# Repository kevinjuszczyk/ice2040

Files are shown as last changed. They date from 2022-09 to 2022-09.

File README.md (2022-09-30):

# ICE2040
ICE40UP5K FPGA + RP2040 Hacker Board
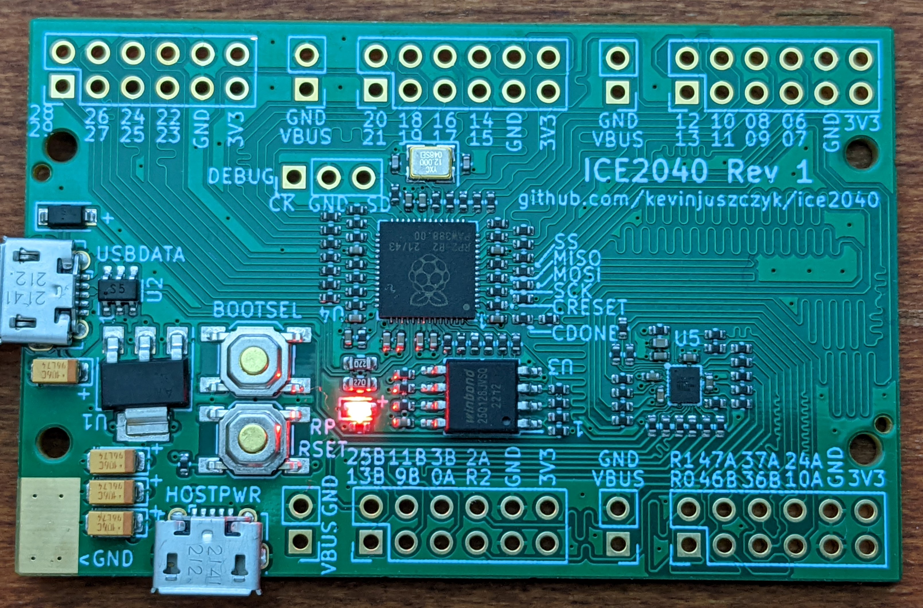
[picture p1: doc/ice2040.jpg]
ice2040


## Overview
The ICE2040 combines a Lattice ICE40UP5K FPGA with a Raspberry Pi RP2040. The RP2040 is used to configure the ICE40 SRAM, and optionally provide a clock or host communication. Pmod connectors are provided for both the ICE40 and RP2040, with the rightmost connectors lined up in such a way that up to 16 additional lines between the ICE40 and RP2040 can be bridged together using a PCB or ribbon cable.

## Background
A friend expressed an interest in implementing a RISC-V processor using an FPGA, something like [learn-fpga](https://github.com/BrunoLevy/learn-fpga/blob/master/FemtoRV/TUTORIALS/FROM_BLINKER_TO_RISCV/README.md). Due to the ongoing parts shortage, many of the low-end FPGA dev boards are either out of stock, or have moved out of the pocket change price range. With an eye toward building a board using whatever might still be in stock, I found that the major retailers have many thousands of ICE40 parts in fine pitch BGA packages. I started playing around in KiCad with the ICE40UP5K-UWG30 (30-ball 0.4mm pitch) part to see if there was a way to fan out enough of the pins to make a reasonably useful board. By modifying the shape of the pads, I was able to achieve a complete fanout that can be fabricated with JLCPCB's 4-layer process. Most boards like this use an FTDI serial converter for host communication and FPGA configuration, but these have also been hard to get. I decided to use an RP2040 for these functions, since they are in stock and much less expensive. 
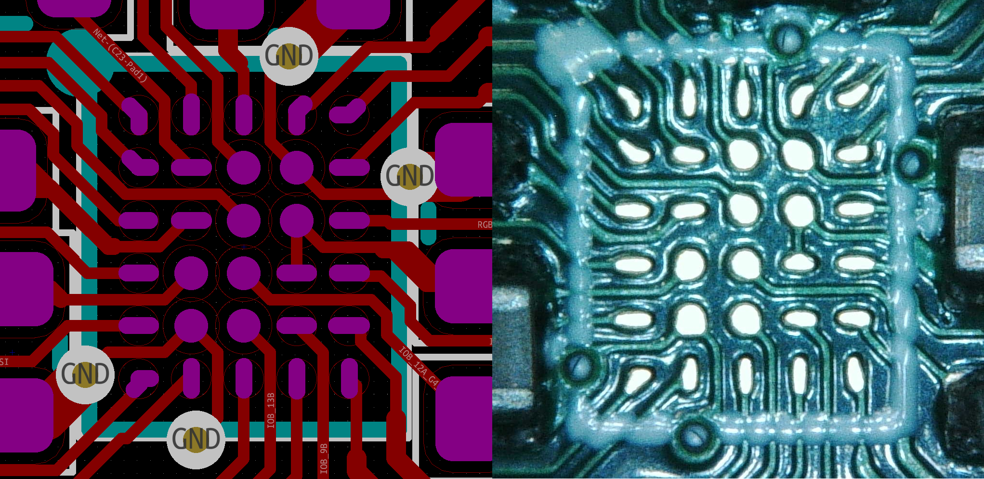
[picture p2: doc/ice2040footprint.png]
ice2040footprint


## Build
#### PCB
The board can be fabricated using [JLCPCB's](https://jlcpcb.com/) 4-layer process, and all components assembled (except for the ICE40 and Pmod headers) using their Economic PCBA service. [Jlcfab.zip](./kicad/jlcfab.zip) contains the fabrication files including the BOM, footprint position, drill, and Gerber files. [Jlcboardsettings.txt](./kicad/jlcboardsettings.txt) shows how to configure the JLCPCB order screen. Note that you want to specify the technical review (Confirm Production Files) for both the board fabrication and assembly. This will let JLCPCB adjust the board traces and parts orientation as needed.

NOTE: If you haven't soldered BGA packages before, this is *not* a good one to start with.
1. When the board arrives, check that the RP2040 is functioning correctly by plugging it into the USB port of your PC. A new removable drive should pop up with the volume name of RPI-RP2.
2. Unplug the board.
3. To hand-solder the ICE40, cover the pads of the ICE40 footprint with a thin layer of tacky flux. If too much flux is used, it will boil when heated and dislodge the balls from the package. 
4. Smear a thin layer of solder paste on a flat metal surface, and then press the ICE40 into it. The idea is to get some paste to stick to the balls so that when heat is applied, the paste will flow down and pool on the pads. 
5. Place the ICE40 on the board and line up the package inside the silkscreen while making sure it stays flat on the board. 
6. Reflow either with an oven or by using a hotplate underneath and a heat gun above. 
7. Check that all pins are connected by using the multimeter diode check. Connect the positive lead to board ground, and then touch each ICE40 Pmod pad with the negative lead. A good connection will show a voltage drop between 0.5 to 0.7 volts. Test for continuity between the power rails and ground to make sure they are not shorted. 
8. If you find an open connection, it may be possible to save the part. Dissolve some tacky flux with an equal amount of 99% isopropyl. Drip this mixture around the perimeter of the part so that it wicks underneath. Soak up any excess with a paper towel, and let the flux dry for several hours. Reflow again.

#### Software
1. Hold down the BOOTSEL button on the board while you plug the board into your PC. Once the RPI-RP2 drive pops up, you can release the button.
2. Download the latest release of [CircuitPython](https://circuitpython.org/board/raspberry_pi_pico/)
3. Copy the .UF2 file to the RPI-RP2 drive.
4. The ICE2040 will reboot and a drive labeled CIRCUITPY will pop up.
5. Copy the [top_bitmap.bin](./icecube2/multiblink/multiblink_Implmnt/sbt/outputs/bitmap/top_bitmap.bin) file to the CIRCUITPY drive. This is an ICE40 FPGA bitstream designed to blink several LEDs on the bottom center Pmod port (labeled 25B, 13B, etc.)
6. Copy the [code.py](./circuitpython/code.py) file to the CIRCUITPY drive, overwriting the existing file. This is a python script designed to upload the top_bitmap.bin file into the ICE40.
7. If you have an LED Pmod plugged into the bottom center Pmod port, you should now see several LEDs blinking at various rates. A multimeter can also be used to check for correct operation. Pins 13B or 25B change slowly enough to show the voltage alternate between 0 and 3.3 volts.
8. CircuitPython will automatically run the code.py script whenever a file on the CIRCUITPY drive is changed (including top_bitmap.bin). A serial port is also provided for communication with the host PC. See the CircuitPython [documentation](https://learn.adafruit.com/welcome-to-circuitpython) for details.


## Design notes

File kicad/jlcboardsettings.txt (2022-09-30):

Base Material: FR-4

Layers: 4

Dimension: 63.5 mm* 40.6 mm

Product Type: Industrial/Consumer electronics

Different Design: 1

Delivery Fomat: Single PCB

PCB Thickness: 1.6

Impedance: yes JLC3313

PCB Color: Green

Silkscreen: White

Surface Finish: ENIG

Deburring/Edge rounding: No

Outer Copper Weight: 1

Inner Copper Weight: 0.5

Gold Fingers: No

Flying Probe Test: Fully Test

Castellated Holes: no

Remove Order Number: No

Min hole size/diameter:0.2/0.45mm↑

4-Wire Kelvin Test:No

Material Type:FR4-Standard Tg 130-140C

Paper between PCBs:No

Appearance Quality:IPC Class 2 Standard

Confirm Production file:Yes

Silkscreen Technology:Ink-jet/Screen Printing Silkscreen

Package Box:With JLCPCB logo

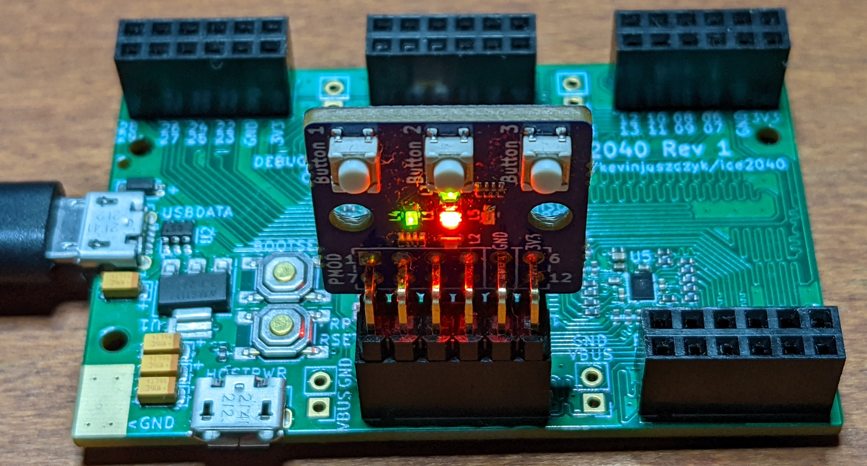
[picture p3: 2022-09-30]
doc/ice2040bg.png

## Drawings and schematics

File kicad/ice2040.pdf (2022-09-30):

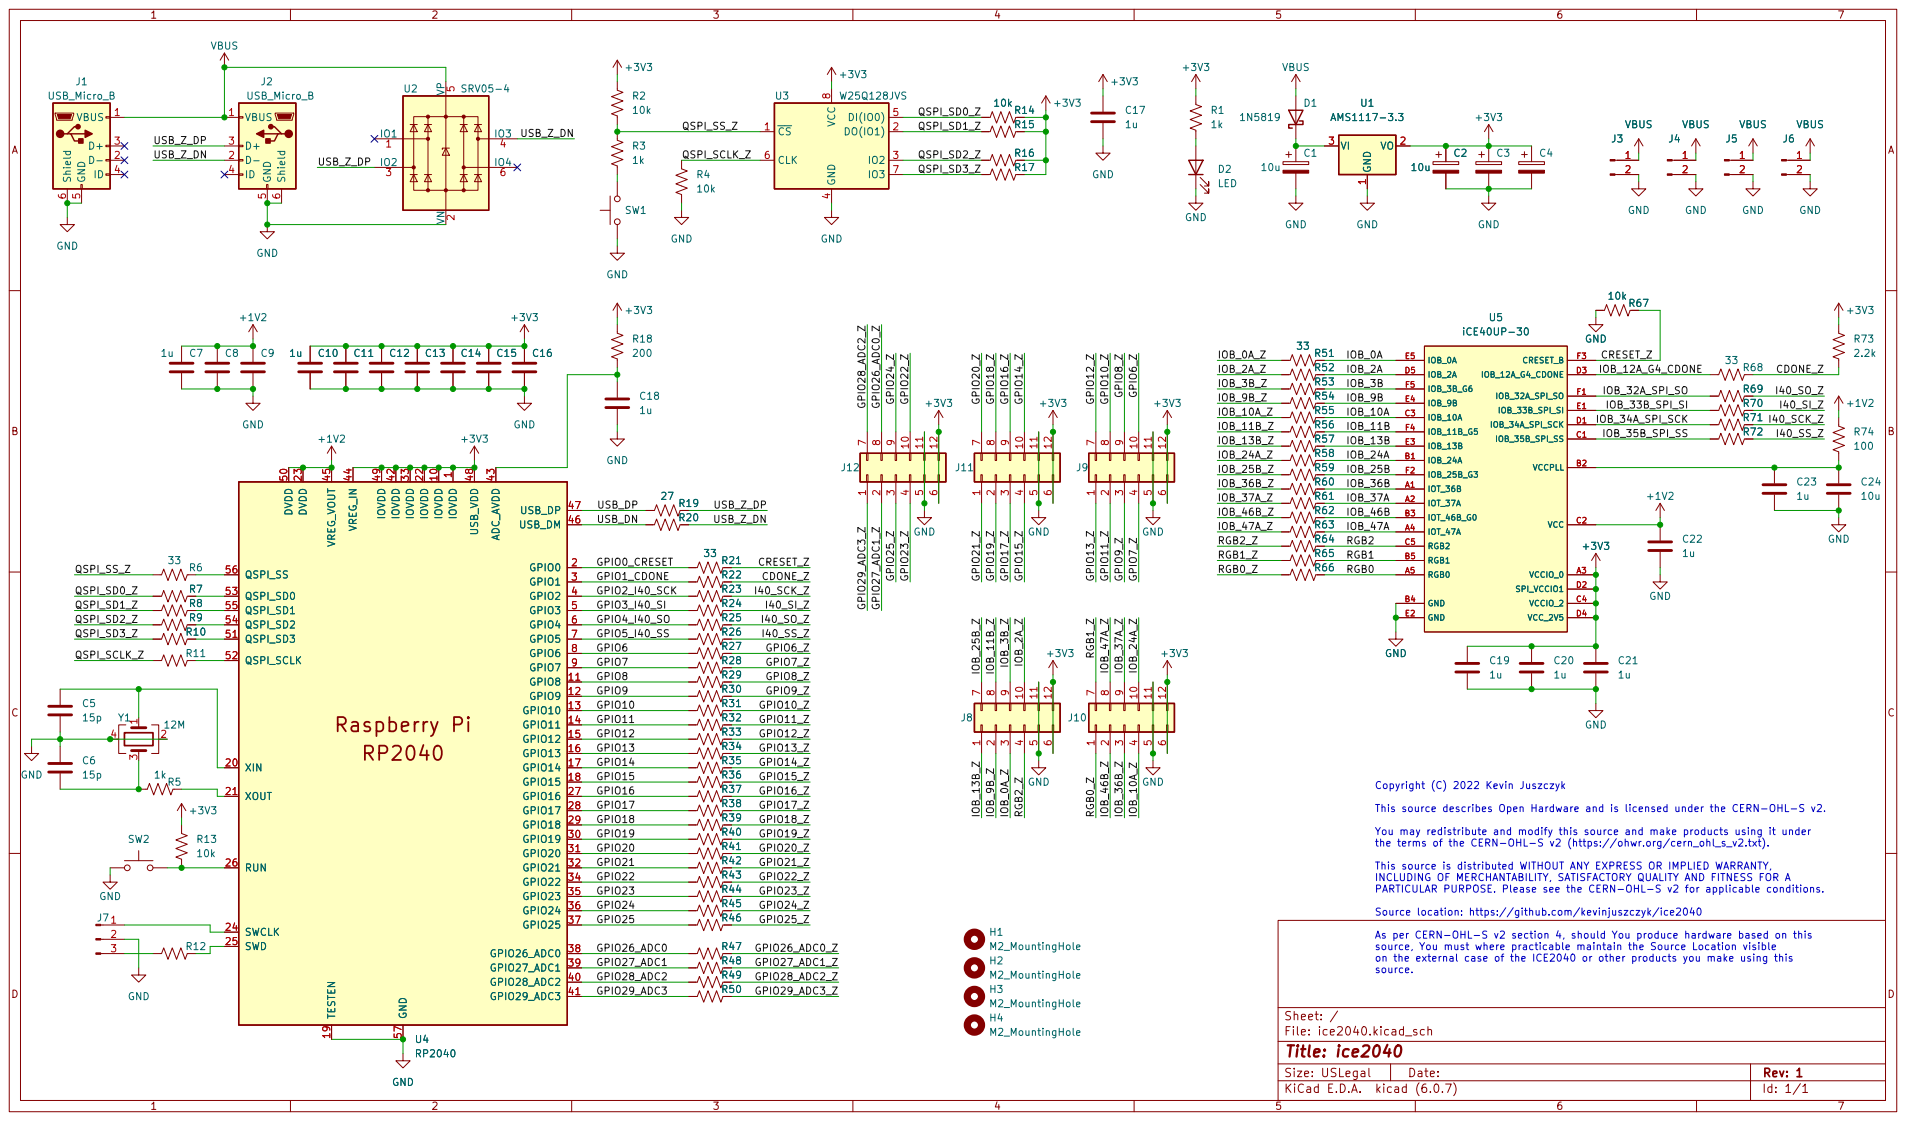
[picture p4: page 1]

1 IOVDD 10 GPIO8 11 GPIO9 12 GPIO10 13 GPIO11 14 GPIO12 15 GPIO13 16 GPIO14 17 GPIO15 18 TESTEN 19 GPIO0 2 XIN 20 XOUT 21 IOVDD 22 DVDD 23 SWCLK 24 SWD 25 RUN 26 GPIO16 27 GPIO17 28 GPIO18 29 GPIO1 3 GPIO19 30 GPIO20 31 GPIO21 32 IOVDD 33 GPIO22 34 GPIO23 35 GPIO24 36 GPIO25 37 GPIO26_ADC0 38 GPIO27_ADC1 39 GPIO2 4 GPIO28_ADC2 40 GPIO29_ADC3 41 IOVDD 42 ADC_AVDD 43 VREG_IN 44 VREG_VOUT 45 USB_DM 46 USB_DP 47 USB_VDD 48 IOVDD 49 GPIO3 5 DVDD 50 QSPI_SD3 51 QSPI_SCLK 52 QSPI_SD0 53 QSPI_SD2 54 QSPI_SD1 55 QSPI_SS 56 GND 57 GPIO4 6 GPIO5 7 GPIO6 8 GPIO7 9 U4RP2040

1 IOVDD 10 GPIO8 11 GPIO9 12 GPIO10 13 GPIO11 14 GPIO12 15 GPIO13 16 GPIO14 17 GPIO15 18 TESTEN 19 GPIO0 2 XIN 20 XOUT 21 IOVDD 22 DVDD 23 SWCLK 24 SWD 25 RUN 26 GPIO16 27 GPIO17 28 GPIO18 29 GPIO1 3 GPIO19 30 GPIO20 31 GPIO21 32 IOVDD 33 GPIO22 34 GPIO23 35 GPIO24 36 GPIO25 37 GPIO26_ADC0 38 GPIO27_ADC1 39 GPIO2 4 GPIO28_ADC2 40 GPIO29_ADC3 41 IOVDD 42 ADC_AVDD 43 VREG_IN 44 VREG_VOUT 45 USB_DM 46 USB_DP 47 USB_VDD 48 IOVDD 49 GPIO3 5 DVDD 50 QSPI_SD3 51 QSPI_SCLK 52 QSPI_SD0 53 QSPI_SD2 54 QSPI_SD1 55 QSPI_SS 56 GND 57 GPIO4 6 GPIO5 7 GPIO6 8 GPIO7 9 R19 27 R20 R22 R21 33 R24 R23 R27 R26 R25 R42 R44 R41 R39 R40 R43 R45 R46 R47 R50 R49 R48

This source describes Open Hardware and is licensed under the CERN-OHL-S v2.

You may redistribute and modify this source and make products using it under
the terms of the CERN-OHL-S v2 (https://ohwr.org/cern_ohl_s_v2.txt). This source is distributed WITHOUT ANY EXPRESS OR IMPLIED WARRANTY,

INCLUDING OF MERCHANTABILITY, SATISFACTORY QUALITY AND FITNESS FOR A PARTICULAR PURPOSE. Please see the CERN-OHL-S v2 for applicable conditions.

Source location: https://github.com/kevinjuszczyk/ice2040

As per CERN-OHL-S v2 section 4, should You produce hardware based on this
source, You must where practicable maintain the Source Location visible
on the external case of the ICE2040 or other products you make using this source.

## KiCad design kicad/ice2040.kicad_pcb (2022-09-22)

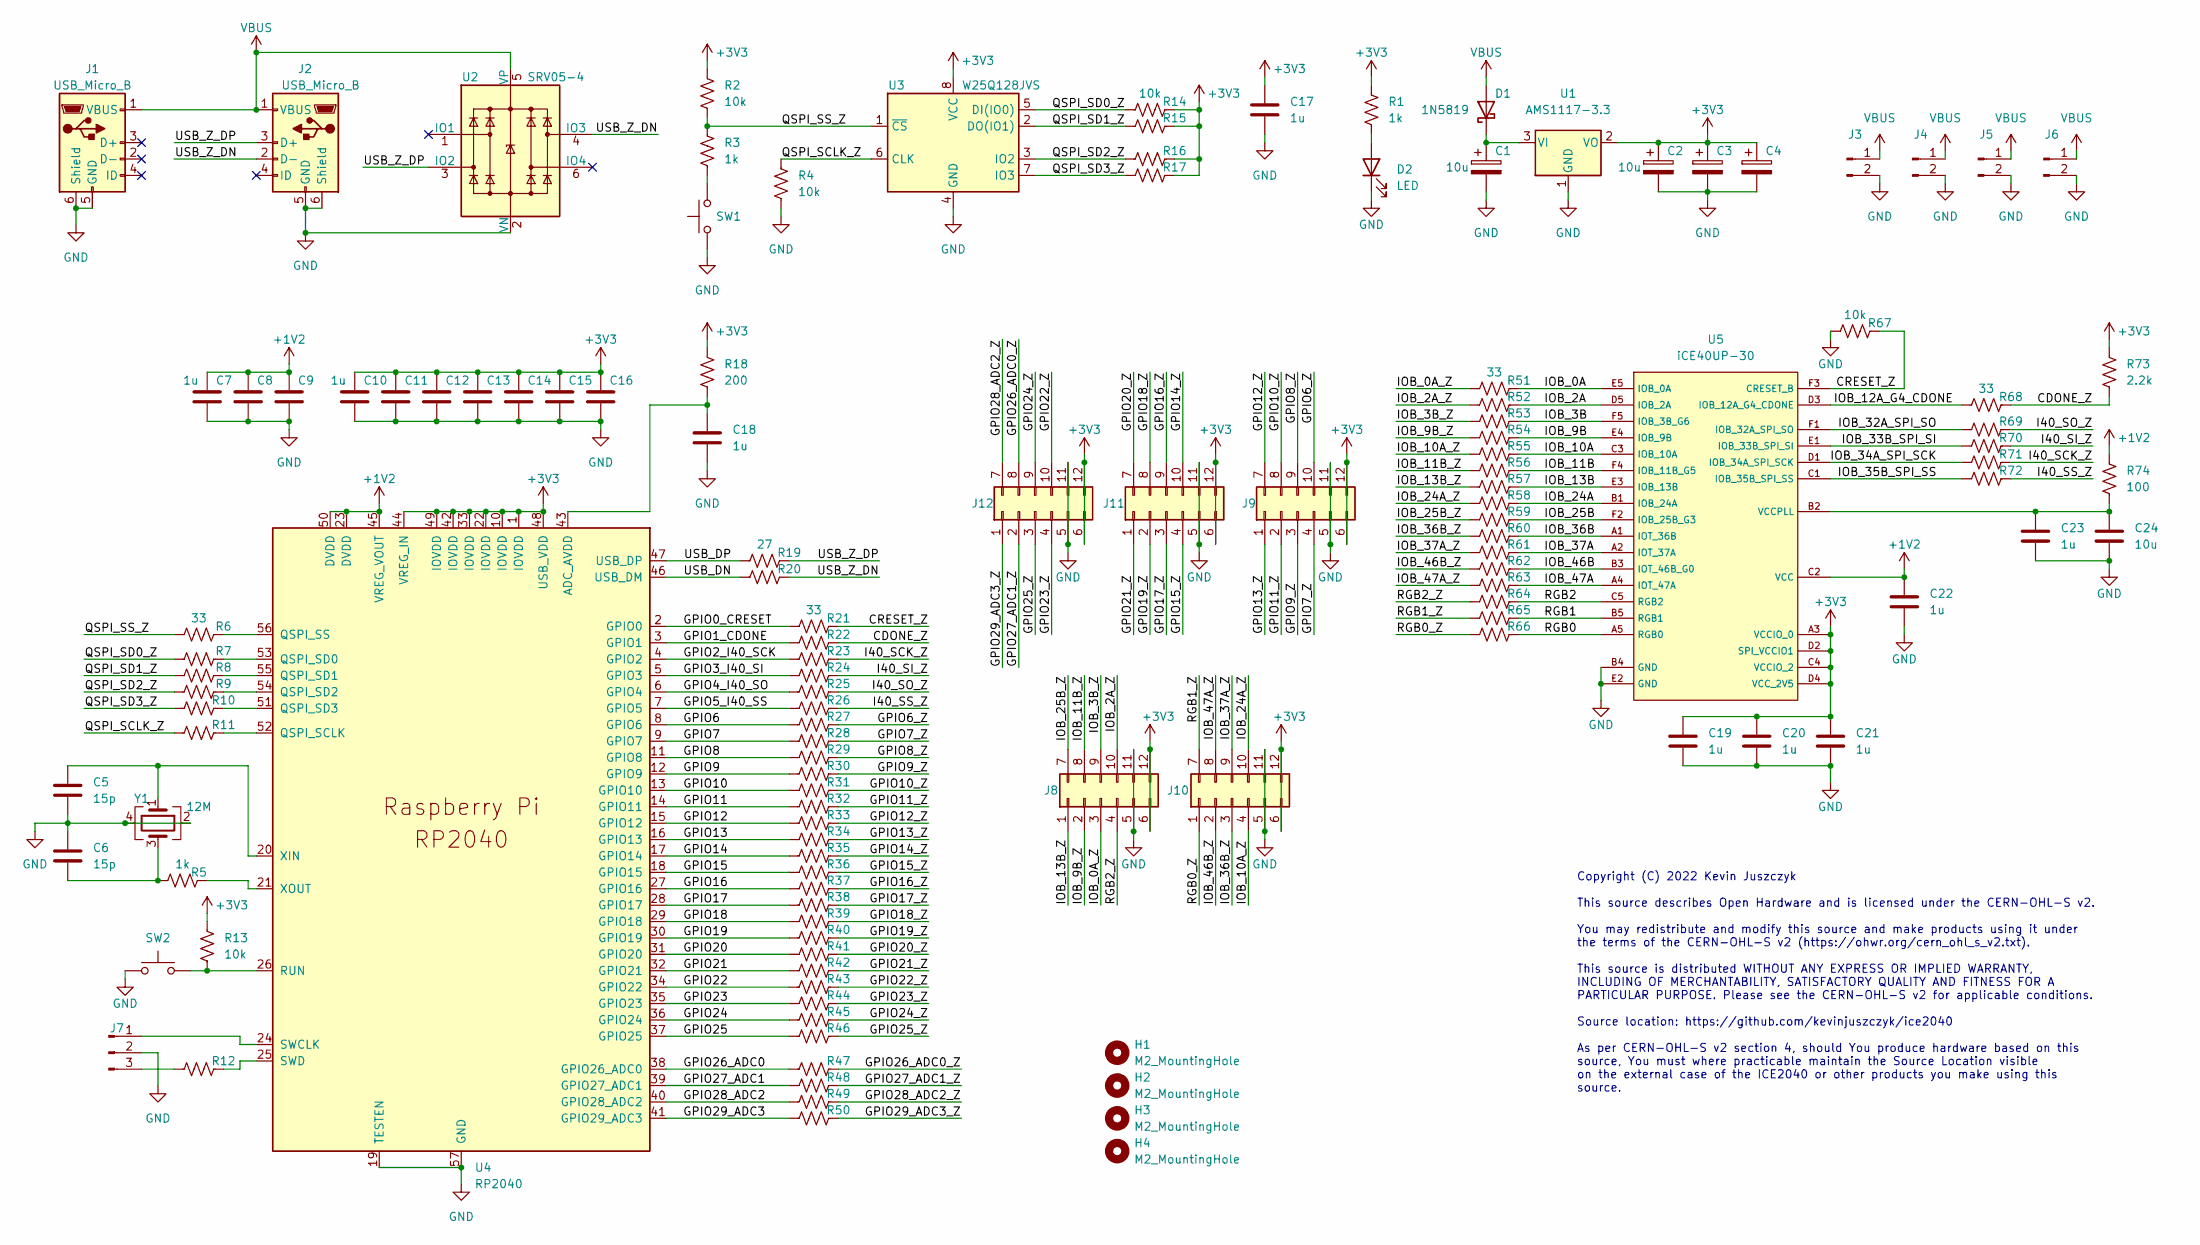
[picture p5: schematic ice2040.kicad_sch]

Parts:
C1, C2, C3, C4: 10u; CP_EIA-3216-18_Kemet-A; LCSC C7171
C5, C6: 15p; C_0402_1005Metric; LCSC C1548
C7, C8, C9, C10, C11, C12, C13, C14, C15, C16, C17, C18, C19, C20, C21, C22, C23: 1u; C_0402_1005Metric; LCSC C52923
C24: 10u; C_0402_1005Metric; LCSC C15525
D1: 1N5819; D_SOD-123; LCSC C8598
D2: LED; D_0603_1608Metric; LCSC C2286
H1, H2, H3, H4: M2_MountingHole; MountingHole_2.2mm_M2_ISO7380
J1, J2: USB_Micro_B; USB_Micro-B_Molex-105017-0001; LCSC C136000
J3, J4, J5, J6: 1x02_P2.54; PinHeader_1x02_P2.54mm_Vertical
J7: 1x03_P2.54; PinHeader_1x03_P2.54mm_Vertical
J8, J9, J10, J11, J12: PMOD_HOST
R1, R3, R5: 1k; R_0402_1005Metric; LCSC C11702
R2, R4, R13, R14, R15, R16, R17, R67: 10k; R_0402_1005Metric; LCSC C25744
R6, R7, R8, R9, R10, R11, R12, R21, R22, R23, R24, R25, R26, R27, R28, R29, R30, R31, R32, R33, R34, R35, R36, R37, R38, R39, R40, R41, R42, R43, R44, R45, R46, R47, R48, R49, R50, R51, R52, R53, R54, R55, R56, R57, R58, R59, R60, R61, R62, R63, R64, R65, R66, R68, R69, R70, R71, R72: 33; R_0402_1005Metric; LCSC C25105
R18: 200; R_0402_1005Metric; LCSC C25087
R19, R20: 27; R_0603_1608Metric; LCSC C25190
R73: 2.2k; R_0402_1005Metric; LCSC C25879
R74: 100; R_0402_1005Metric; LCSC C25076
SW1, SW2: SW_Push; SW_SPST_SKQG_WithoutStem; LCSC C318884
U1: AMS1117-3.3; SOT-223-3_TabPin2; LCSC C6186
U2: SRV05-4; SOT-23-6; LCSC C85364
U3: W25Q128JVS; SOIC-8_5.23x5.23mm_P1.27mm; LCSC C97521
U4: RP2040; QFN-56-1EP_7x7mm_P0.4mm_EP3.2x3.2mm_MoreThermalVias; LCSC C2040
U5: iCE40UP-30; BGA-30_5x6_2.114x2.537mm; LCSC C1519053
Y1: 12M; Crystal_SMD_SeikoEpson_FA238-4Pin_3.2x2.5mm; LCSC C9002

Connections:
+1V2: C7.1, C8.1, C9.1, C22.1, R74.2, U4.23 (DVDD), U4.45 (VREG_VOUT), U4.50 (DVDD), U5.C2 (VCC)
+3V3: C2.1, C3.1, C4.1, C10.1, C11.1, C12.1, C13.1, C14.1, C15.1, C16.1, C17.1, C19.1, C20.1, C21.1, J8.6, J8.12, J9.6, J9.12, J10.6, J10.12, J11.6, J11.12, J12.6, J12.12, R1.2, R2.2, R13.2, R14.1, R15.1, R16.1, R17.1, R18.2, R73.2, U1.2 (VO), U3.8 (VCC), U4.1 (IOVDD), U4.10 (IOVDD), U4.22 (IOVDD), U4.33 (IOVDD), U4.42 (IOVDD), U4.44 (VREG_IN), U4.48 (USB_VDD), U4.49 (IOVDD), U5.A3 (VCCIO_0), U5.C4 (VCCIO_2), U5.D2 (SPI_VCCIO1), U5.D4 (VCC_2V5)
/CDONE_Z: R22.1, R68.1, R73.1
/CRESET_Z: R21.1, R67.1, U5.F3 (CRESET_B)
/GPIO0_CRESET: R21.2, U4.2 (GPIO0)
/GPIO1_CDONE: R22.2, U4.3 (GPIO1)
/GPIO2_I40_SCK: R23.2, U4.4 (GPIO2)
/GPIO3_I40_SI: R24.2, U4.5 (GPIO3)
/GPIO4_I40_SO: R25.2, U4.6 (GPIO4)
/GPIO5_I40_SS: R26.2, U4.7 (GPIO5)
/GPIO6: R27.2, U4.8 (GPIO6)
/GPIO6_Z: J9.10, R27.1
/GPIO7: R28.2, U4.9 (GPIO7)
/GPIO7_Z: J9.4, R28.1
/GPIO8: R29.2, U4.11 (GPIO8)
/GPIO8_Z: J9.9, R29.1
/GPIO9: R30.2, U4.12 (GPIO9)
/GPIO9_Z: J9.3, R30.1
/GPIO10: R31.2, U4.13 (GPIO10)
/GPIO10_Z: J9.8, R31.1
/GPIO11: R32.2, U4.14 (GPIO11)
/GPIO11_Z: J9.2, R32.1
/GPIO12: R33.2, U4.15 (GPIO12)
/GPIO12_Z: J9.7, R33.1
/GPIO13: R34.2, U4.16 (GPIO13)
/GPIO13_Z: J9.1, R34.1
/GPIO14: R35.2, U4.17 (GPIO14)
/GPIO14_Z: J11.10, R35.1
/GPIO15: R36.2, U4.18 (GPIO15)
/GPIO15_Z: J11.4, R36.1
/GPIO16: R37.2, U4.27 (GPIO16)
/GPIO16_Z: J11.9, R37.1
/GPIO17: R38.2, U4.28 (GPIO17)
/GPIO17_Z: J11.3, R38.1
/GPIO18: R39.2, U4.29 (GPIO18)
/GPIO18_Z: J11.8, R39.1
/GPIO19: R40.2, U4.30 (GPIO19)
/GPIO19_Z: J11.2, R40.1
/GPIO20: R41.2, U4.31 (GPIO20)
/GPIO20_Z: J11.7, R41.1
/GPIO21: R42.2, U4.32 (GPIO21)
/GPIO21_Z: J11.1, R42.1
/GPIO22: R43.2, U4.34 (GPIO22)
/GPIO22_Z: J12.10, R43.1
/GPIO23: R44.2, U4.35 (GPIO23)
/GPIO23_Z: J12.4, R44.1
/GPIO24: R45.2, U4.36 (GPIO24)
/GPIO24_Z: J12.9, R45.1
/GPIO25: R46.2, U4.37 (GPIO25)
/GPIO25_Z: J12.3, R46.1
/GPIO26_ADC0: R47.2, U4.38 (GPIO26_ADC0)
/GPIO26_ADC0_Z: J12.8, R47.1
/GPIO27_ADC1: R48.2, U4.39 (GPIO27_ADC1)
/GPIO27_ADC1_Z: J12.2, R48.1
/GPIO28_ADC2: R49.2, U4.40 (GPIO28_ADC2)
/GPIO28_ADC2_Z: J12.7, R49.1
/GPIO29_ADC3: R50.2, U4.41 (GPIO29_ADC3)
/GPIO29_ADC3_Z: J12.1, R50.1
/I40_SCK_Z: R23.1, R71.1
/I40_SI_Z: R24.1, R70.1
/I40_SO_Z: R25.1, R69.1
/I40_SS_Z: R26.1, R72.1
/IOB_0A: R51.1, U5.E5 (IOB_0A)
/IOB_0A_Z: J8.3, R51.2
/IOB_2A: R52.1, U5.D5 (IOB_2A)
/IOB_2A_Z: J8.10, R52.2
/IOB_3B: R53.1, U5.F5 (IOB_3B_G6)
/IOB_3B_Z: J8.9, R53.2
/IOB_9B: R54.1, U5.E4 (IOB_9B)
/IOB_9B_Z: J8.2, R54.2
/IOB_10A: R55.1, U5.C3 (IOB_10A)
/IOB_10A_Z: J10.4, R55.2
/IOB_11B: R56.1, U5.F4 (IOB_11B_G5)
/IOB_11B_Z: J8.8, R56.2
/IOB_12A_G4_CDONE: R68.2, U5.D3 (IOB_12A_G4_CDONE)
/IOB_13B: R57.1, U5.E3 (IOB_13B)
/IOB_13B_Z: J8.1, R57.2
/IOB_24A: R58.1, U5.B1 (IOB_24A)
/IOB_24A_Z: J10.10, R58.2
/IOB_25B: R59.1, U5.F2 (IOB_25B_G3)
/IOB_25B_Z: J8.7, R59.2
/IOB_32A_SPI_SO: R69.2, U5.F1 (IOB_32A_SPI_SO)
/IOB_33B_SPI_SI: R70.2, U5.E1 (IOB_33B_SPI_SI)
/IOB_34A_SPI_SCK: R71.2, U5.D1 (IOB_34A_SPI_SCK)
/IOB_35B_SPI_SS: R72.2, U5.C1 (IOB_35B_SPI_SS)
/IOB_36B: R60.1, U5.A1 (IOT_36B)
/IOB_36B_Z: J10.3, R60.2
/IOB_37A: R61.1, U5.A2 (IOT_37A)
/IOB_37A_Z: J10.9, R61.2
/IOB_46B: R62.1, U5.B3 (IOT_46B_G0)
/IOB_46B_Z: J10.2, R62.2
/IOB_47A: R63.1, U5.A4 (IOT_47A)
/IOB_47A_Z: J10.8, R63.2
/QSPI_SCLK_Z: R4.2, R11.2, U3.6 (CLK)
/QSPI_SD0_Z: R7.2, R14.2, U3.5 (DI(IO0))
/QSPI_SD1_Z: R8.2, R15.2, U3.2 (DO(IO1))
/QSPI_SD2_Z: R9.2, R16.2, U3.3 (IO2)
/QSPI_SD3_Z: R10.2, R17.2, U3.7 (IO3)
/QSPI_SS_Z: R2.1, R3.2, R6.2, U3.1 (~CS)
/RGB0: R66.1, U5.A5 (RGB0)
/RGB0_Z: J10.1, R66.2
/RGB1: R65.1, U5.B5 (RGB1)
/RGB1_Z: J10.7, R65.2
/RGB2: R64.1, U5.C5 (RGB2)
/RGB2_Z: J8.4, R64.2
/USB_DN: R20.2, U4.46 (USB_DM)
/USB_DP: R19.2, U4.47 (USB_DP)
/USB_Z_DN: J2.2 (D-), R20.1, U2.4 (IO3)
/USB_Z_DP: J2.3 (D+), R19.1, U2.3 (IO2)
GND: C1.2, C2.2, C3.2, C4.2, C5.2, C6.1, C7.2, C8.2, C9.2, C10.2, C11.2, C12.2, C13.2, C14.2, C15.2, C16.2, C17.2, C18.2, C19.2, C20.2, C21.2, C22.2, C23.2, C24.2, D2.1 (K), J1.5 (GND), J1.6 (Shield), J2.5 (GND), J2.6 (Shield), J3.2, J4.2, J5.2, J6.2, J7.2, J8.5, J8.11, J9.5, J9.11, J10.5, J10.11, J11.5, J11.11, J12.5, J12.11, R4.1, R67.2, SW1.1, SW2.1, U1.1 (GND), U2.2 (VN), U3.4 (GND), U4.19 (TESTEN), U4.57 (GND), U5.B4 (GND), U5.E2 (GND), Y1.2, Y1.4
unnamed: C1.1, D1.1 (K), U1.3 (VI)
unnamed: C5.1, U4.20 (XIN), Y1.1
unnamed: C6.2, R5.2, Y1.3
unnamed: C18.1, R18.1, U4.43 (ADC_AVDD)
unnamed: C23.1, C24.1, R74.1, U5.B2 (VCCPLL)
unnamed: D2.2 (A), R1.1
unnamed: J7.1, U4.24 (SWCLK)
unnamed: J7.3, R12.2
unnamed: R3.1, SW1.2
unnamed: R5.1, U4.21 (XOUT)
unnamed: R6.1, U4.56 (QSPI_SS)
unnamed: R7.1, U4.53 (QSPI_SD0)
unnamed: R8.1, U4.55 (QSPI_SD1)
unnamed: R9.1, U4.54 (QSPI_SD2)
unnamed: R10.1, U4.51 (QSPI_SD3)
unnamed: R11.1, U4.52 (QSPI_SCLK)
unnamed: R12.1, U4.25 (SWD)
unnamed: R13.1, SW2.2, U4.26 (RUN)
VBUS: D1.2 (A), J1.1 (VBUS), J2.1 (VBUS), J3.1, J4.1, J5.1, J6.1, U2.5 (VP)

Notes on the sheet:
Copyright (C) 2022 Kevin Juszczyk This source describes Open Hardware and is licensed under the CERN-OHL-S v2. You may redistribute and modify this source and make products using it under the terms of the CERN-OHL-S v2 (https://ohwr.org/cern_ohl_s_v2.txt). This source is distributed WITHOUT ANY EXP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

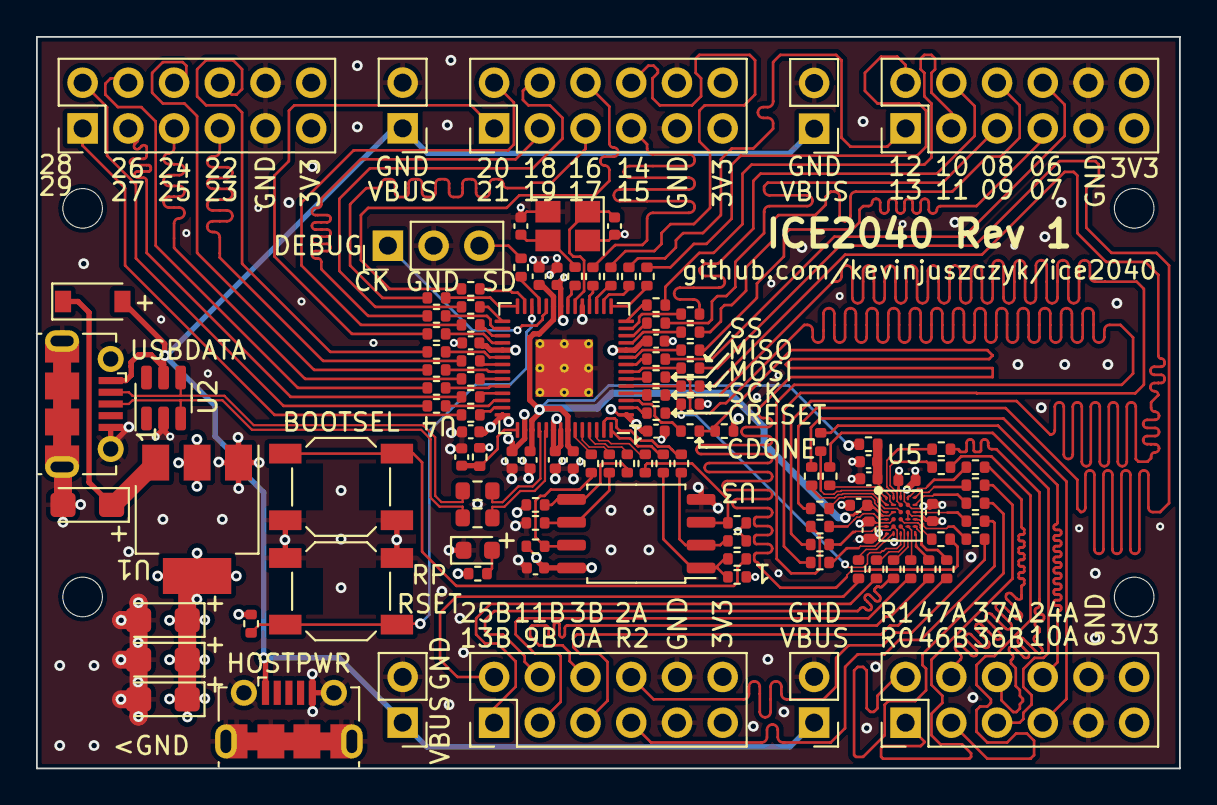
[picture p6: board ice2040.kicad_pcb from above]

Board: 4 copper layers, 63.5 x 40.6 mm, 124 parts (0 on the bottom side), 129 nets.

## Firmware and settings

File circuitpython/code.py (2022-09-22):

#Copyright (C) 2022 Kevin Juszczyk
#Source location: https://github.com/kevinjuszczyk/ice2040
#
#This program is free software: you can redistribute it and/or modify it under
#the terms of the GNU General Public License as published by the Free Software
#Foundation, either version 3 of the License, or (at your option) any later version.
#
#This program is distributed in the hope that it will be useful, but WITHOUT
#ANY WARRANTY; without even the implied warranty of MERCHANTABILITY or FITNESS
#FOR A PARTICULAR PURPOSE. See the GNU General Public License for more details.
#
#You should have received a copy of the GNU General Public License along with
#this program. If not, see <https://www.gnu.org/licenses/>.

import board
import busio
import digitalio
import io
import time
import supervisor
import pwmio

print("\n**********ICE2040**********")
print("Starting FPGA Configuration...")

creset = digitalio.DigitalInOut(board.GP0)
creset.direction = digitalio.Direction.OUTPUT
creset.value = False

cdone = digitalio.DigitalInOut(board.GP1)
cdone.direction = digitalio.Direction.INPUT
print("CDONE=" + str(cdone.value))

cs = digitalio.DigitalInOut(board.GP5)
cs.direction = digitalio.Direction.OUTPUT

print("Start with CRESET_B and SPI_SS held LOW, wait >200ns.")
cs.value = False
creset.value = False
time.sleep(0.001)

print("CRESET_B brought HIGH and SPI_SS held LOW, wait >1200us.")
creset.value = True
time.sleep(0.002)

#config SPI
spi = busio.SPI(clock=board.GP2, MISO=board.GP4, MOSI=board.GP3)

while not spi.try_lock():
    pass

spi.configure(baudrate=240000000, phase=0, polarity=0)

bitstream = open("top_bitmap.bin",mode='rb')
bitstreambuf = bitstream.read()

print("SPI_SS brought HIGH, cycle SPI_SCK 8 times.")
cs.value = True
spi.write(bytes(8))

print("SPI_SS brought LOW, reading bitstream file into ICE40 SPI_SI pin.")
cs.value = False
spi.write(bitstreambuf)

print("Finished bitstream file, SPI_SS brought HIGH.")
cs.value = True

print("Cycle SPI_SCK 100 times to read CDONE HIGH.")
spi.write(bytes(100))
gotcdone = cdone.value
print("CDONE=" + str(gotcdone))

if gotcdone:
    print("Cycle SPI_SCK 49 times to release FPGA IO for user application.")
    spi.write(bytes(49))
else:
    print("Error configuring FPGA!!")

#clean up GPIO and file
spi.unlock()
bitstream.close()
cs.deinit()
cdone.deinit()

if gotcdone:
    print("12MHz clock from RP2040 GP1 to ICE40 CDONE.")
    #RP2040 GP1/ICE40 CDONE were arbitrarily chosen.
    #RP2040 can output PWM on any pin, and ICE40 can take its clock on any pin.
    #The CDONE pin is connected to a global line meant for clock distribution
    #across the FPGA. This also demonstrates repurposing an FPGA configuration
    #pin after configuration is finished.
    pwm = pwmio.PWMOut(board.GP1, duty_cycle=2 ** 15, frequency=12000000, variable_frequency=False)

print("Type 'x' to terminate program and reset FPGA.")

while True:
    time.sleep(0.1)
    if supervisor.runtime.serial_bytes_available:
        value = input().strip()
        if value == "x":
            break

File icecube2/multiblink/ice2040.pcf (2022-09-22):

set_io IOB_0A  E5
set_io IOB_2A  D5
set_io IOB_3B  F5
set_io IOB_9B  E4
set_io IOB_10A C3
set_io IOB_11B F4
set_io IOB_13B E3
set_io IOB_24A B1
set_io IOB_25B F2
set_io IOB_36B A1
set_io IOB_37A A2
set_io IOB_46B B3
set_io IOB_47A A4
set_io RGB2 C5
set_io RGB1 B5
set_io RGB0 A5

set_io IOB_12A_G4_CDONE D3
set_io IOB_32A_SPI_SO F1
set_io IOB_33B_SPI_SI E1
set_io IOB_34A_SPI_SCK D1
set_io IOB_35B_SPI_SS C1

set_io P1A1  E3
set_io P1A2  E4
set_io P1A3  E5
set_io P1A4  C5
set_io P1A7  F2
set_io P1A8  F4
set_io P1A9  F5
set_io P1A10 D5

set_io P1B1       A5
set_io P1B2       B3
set_io P1B3       A1
set_io P1B4       C3
set_io P1B7       B5
set_io P1B8       A4
set_io P1B9       A2
set_io P1B10      B1

set_io CLK        D3
set_frequency CLK 12
